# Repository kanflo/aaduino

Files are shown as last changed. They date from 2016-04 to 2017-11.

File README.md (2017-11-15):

# The AAduino

<p align="center">
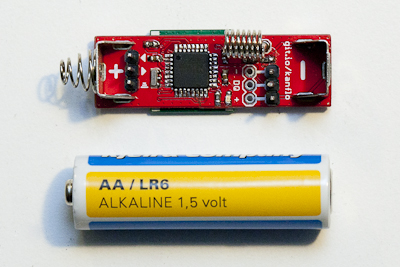
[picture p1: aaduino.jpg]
The AAduino
  
</p>

### News! Don't miss the successor of the AAduino, the [AAduino Zero](https://github.com/kanflo/aaduino-zero).

The AAduino is an wireless Arduino clone the size of an AA battery with Keystone battery terminals rotated 180° to act as positive and negative terminals. It is meant to go inside a 3xAA battery holder creating a very small wireless node.

Powered by an ATMega328p, it is fitted with an RFM69CW companion, two DS18B20 temperature sensors and an indicator LED.

Included in this repository is the schematics, bill of material and a sample program to test the hardware.
If you want solder up one yourself you can buy most of what is needed through the links on the [Kitnic page](https://kitnic.it/boards/github.com/kanflo/aaduino).

If you are looking for an easy way to order the PCBs only, please order from [DirtyPCBs.com](http://dirtypcbs.com/view.php?share=18116&accesskey=5cb9ea9c4754e5c9102b4350393b244e) and I will receive a $1 credit :)

The accompanying blog post is [here](http://johan.kanflo.com/the-aaduino).

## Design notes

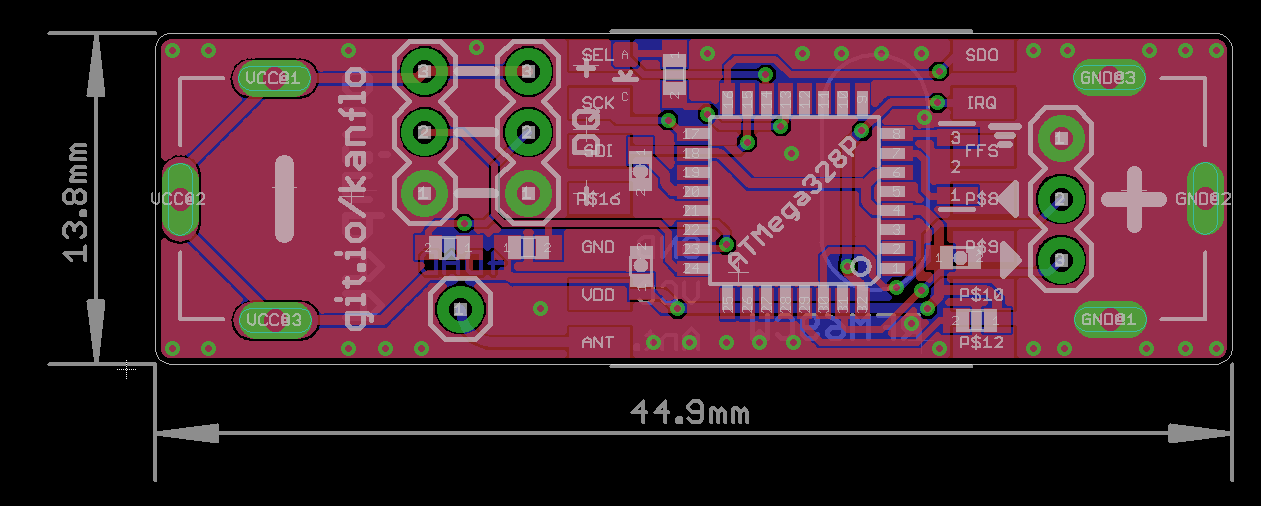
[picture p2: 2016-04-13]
hardware/aaduino-v2.png

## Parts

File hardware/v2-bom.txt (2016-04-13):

Part Value           Device                    Package                              Description           PROD_ID   VALUE     
ANT  M01PTH          M01PTH                    1X01                                 Header 1                                  
C1   0.1uF           0.1UF-25V(+80/-20%)(0603) 0603-CAP                             CAP-00810             CAP-00810 0.1uF     
C2   0.1uF           0.1UF-25V(+80/-20%)(0603) 0603-CAP                             CAP-00810             CAP-00810 0.1uF     
C3   0.1uF           0.1UF-25V(+80/-20%)(0603) 0603-CAP                             CAP-00810             CAP-00810 0.1uF     
J1   KEYSTONE-629    KEYSTONE-629              KEYSTONE_AA_AAA_BATTERY_TERMINAL-629 Keystone 629                              
J2   KEYSTONE-637    KEYSTONE-637              KEYSTONE_AA_AAA_BATTERY_TERMINAL-637 Keystone 637                              
JP1                  M03PTH                    1X03                                 Header 3                                  
JP2                  M03PTH                    1X03                                 Header 3                                  
JP3                  M03PTH                    1X03                                 Header 3                                  
LED1                 LED0603                   LED-0603                             LEDs                                      
R1   10k             RESISTOR0603-RES          0603-RES                             Resistor                                  
R2   1k8             RESISTOR0603-RES          0603-RES                             Resistor                                  
R3   4k7             RESISTOR0603-RES          0603-RES                             Resistor                                  
R4   4k7             RESISTOR0603-RES          0603-RES                             Resistor                                  
U1   ATMEGA328P      ATMEGA328_SMT             TQFP32-08                            32-Pin Atmega328 part IC-09069  ATMEGA328P
U2   RFM12B          RFM12B                    RFM12B                                                                         
U3   RESONATOR_8MHZ  RESONATOR_8MHZ            RESONATOR_SMD                                                                  

Oh, and if you want to build an AAduino, the markings for UART RX/TX got mixed up on the silk screen :-/

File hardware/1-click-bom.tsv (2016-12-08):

References | Qty | Description | Manufacturer | MPN | Digikey | Mouser | RS | Newark | Farnell
LED1 | 1 | LED 0603 | Rohm | SML-D12Y8WT86 | 511-1582-1-ND | 5988150107F | 7008023 | 75R0585 | 1465989
C1, C2, C3 | 3 | 0.1UF 25V 0603 | AVX | 06033C104KAT2A | 478-3714-1-ND | 58106033C104JAT2A | 4646379 | 47Y9715 | 317287
R1 | 1 | Resistor 10k 0603 | Vishay | MCT0603MD1001BP100 | MCT0603-10K-MBCT-ND | 594MCT0603MD1002BP1 | 6845604 | 15R2055 | 2321085
R2 | 1 | Resistor 1.8k 0603 | Panasonic | ERJ-3EKF1801V | P1.80KHCT-ND | 279CPF0603B1K8E1 | 8206782 | 80P3903 | 1697379
R3, R4 | 2 | Resistor 4.7k 0603 | Yageo | RC0603FR-074K7L | 311-4.70KHRCT-ND | 667ERJP03F4701V | 8206865 | 24T7159 | 2281415
U1 | 1 | ATMEGA328 TQFP32 | Atmel | ATMEGA328P-AU | ATMEGA328P-AU-ND | 556ATMEGA328PAU | 6963092 | 68T2935 | 1715486
J1 | 1 | Battery contact, negative | KEYSTONE | 629 | 36-629-ND | 534629 | 2050057 | 98B5924 | 1696977
J2 | 1 | Battery contact, positive | KEYSTONE | 637 | 36-637-ND | 534637 | 3670602 | 99H8361
U3 | 1 | 8 Mhz resonator | Murata | CSTCE8M00G52-R0 | 490-5994-1-ND | 81CSTCE8M00G52R0 | 7214824 | 87X8659 | 2443268
U2 | 1 | RFM69CW module from eBay |  | RFM69CW

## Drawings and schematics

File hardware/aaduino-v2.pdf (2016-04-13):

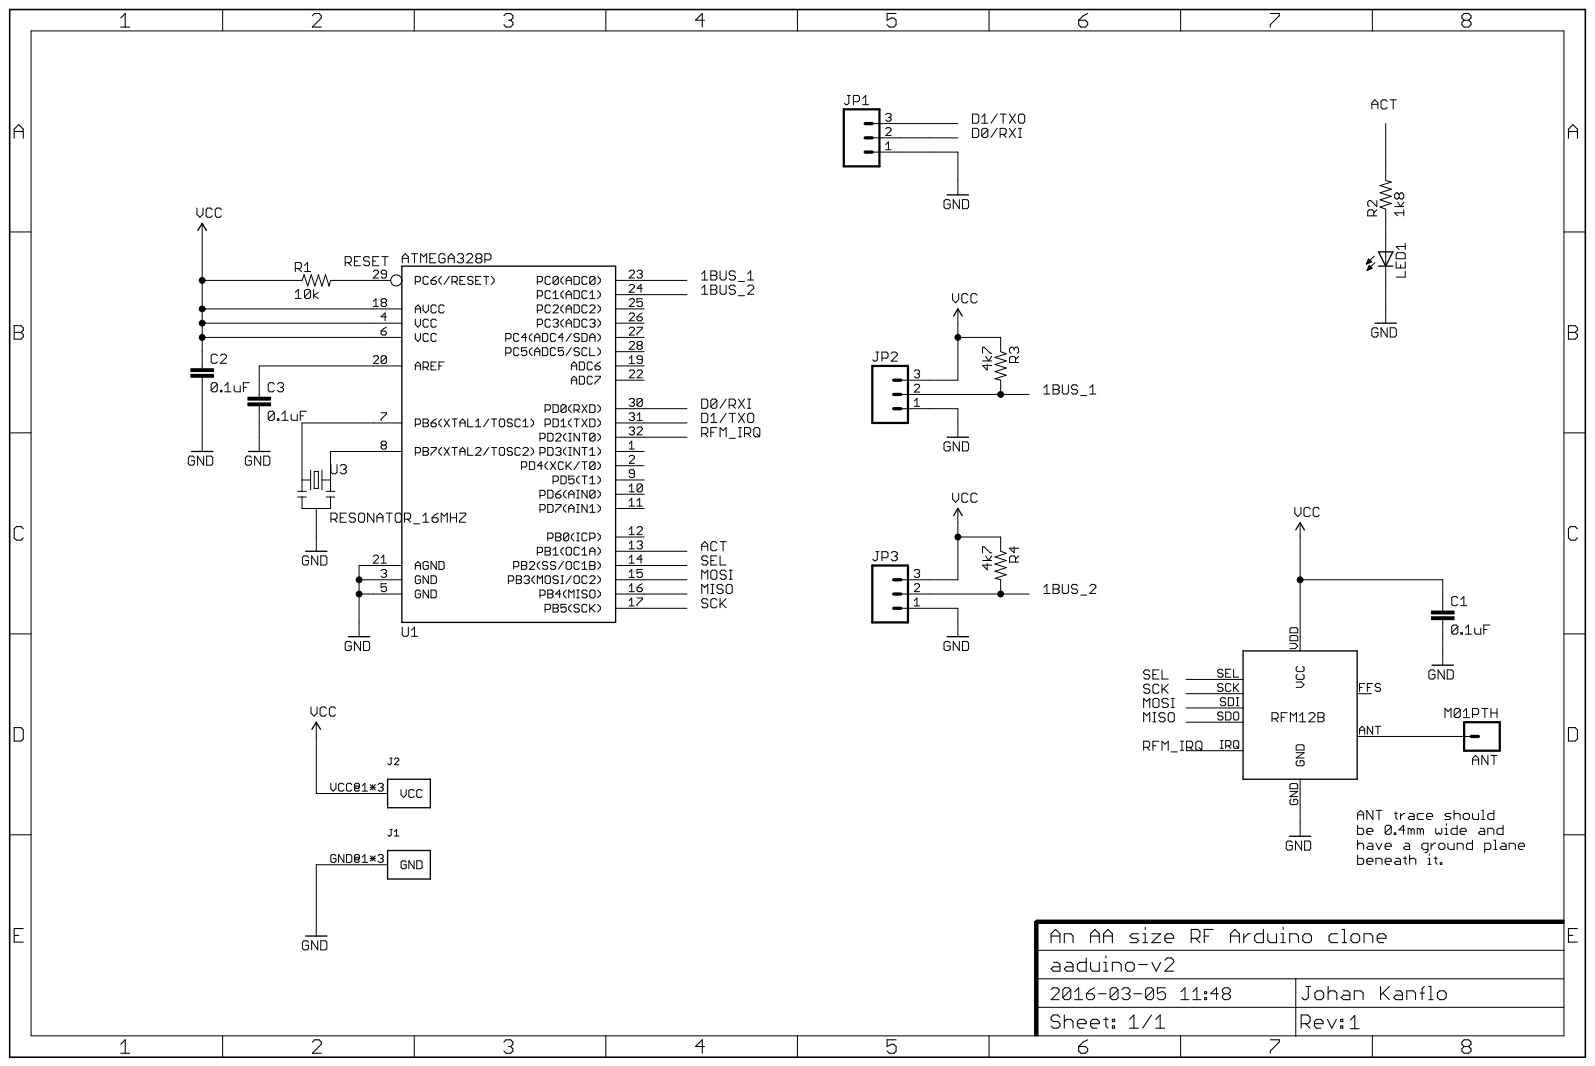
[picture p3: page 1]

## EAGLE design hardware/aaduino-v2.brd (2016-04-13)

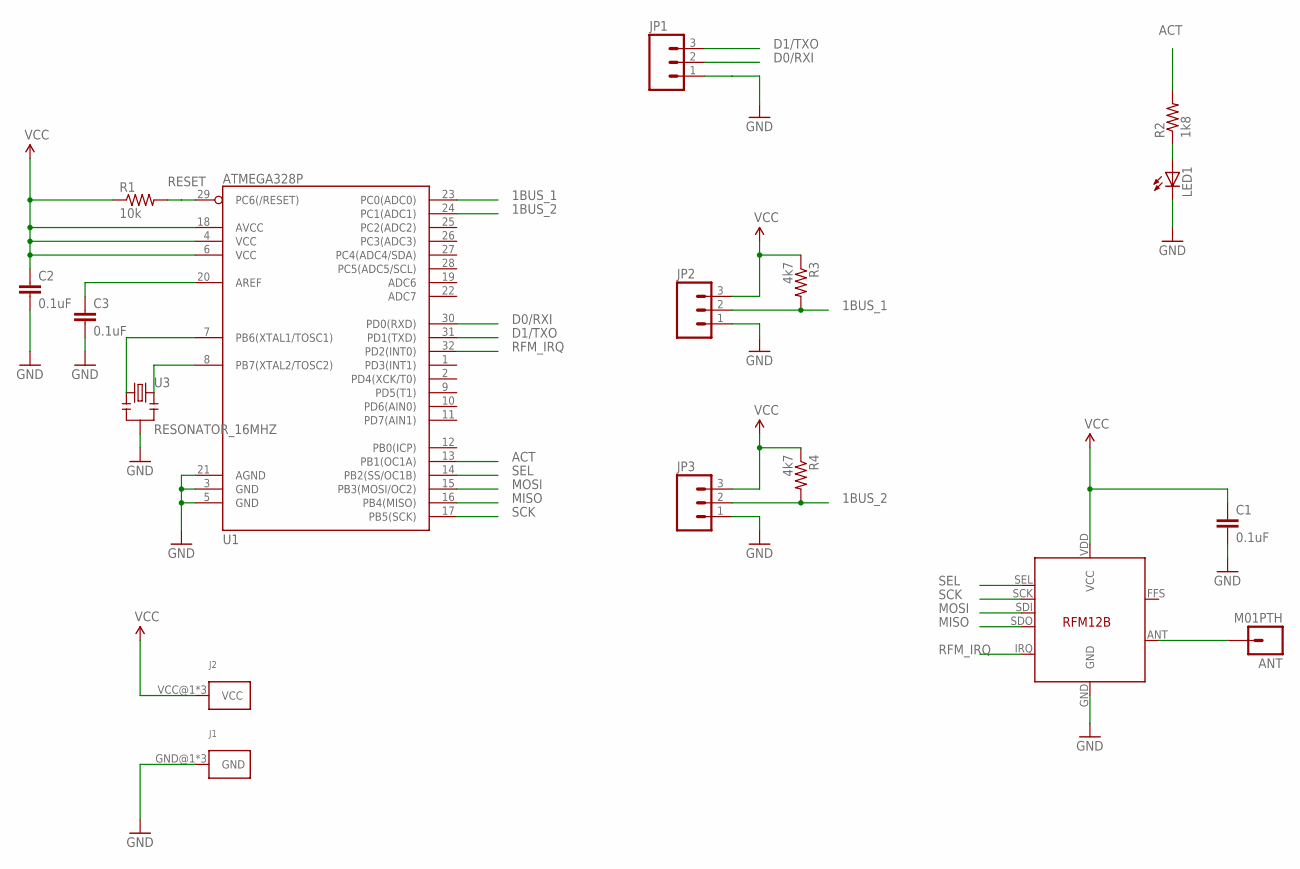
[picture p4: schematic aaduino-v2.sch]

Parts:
ANT: M01PTH; 1X01
C1, C2, C3: 0.1uF; 0603-CAP
J1: KEYSTONE-629; KEYSTONE_AA_AAA_BATTERY_TERMINAL-629
J2: KEYSTONE-637; KEYSTONE_AA_AAA_BATTERY_TERMINAL-637
JP1, JP2, JP3: M03PTH; 1X03
LED1: LED0603; LED-0603
R1: 10k; 0603-RES
R2: 1k8; 0603-RES
R3, R4: 4k7; 0603-RES
U1: ATMEGA328P; TQFP32-08
U2: RFM12B
U3: RESONATOR_16MHZ; RESONATOR_SMD

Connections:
1BUS_1: JP2.2, R3.2, U1.23 (PC0(ADC0))
1BUS_2: JP3.2, R4.2, U1.24 (PC1(ADC1))
ACT: R2.2, U1.13 (PB1(OC1A))
D0/RXI: JP1.2, U1.30 (PD0(RXD))
D1/TXO: JP1.3, U1.31 (PD1(TXD))
GND: C1.2, C2.2, C3.2, J1.GND@1, J1.GND@2, J1.GND@3, JP1.1, JP2.1, JP3.1, LED1.C, U1.3 (GND), U1.5 (GND), U1.21 (AGND), U2.GND, U3.2
MISO: U1.16 (PB4(MISO)), U2.SDO
MOSI: U1.15 (PB3(MOSI/OC2)), U2.SDI
unnamed: LED1.A, R2.1
unnamed: C3.1, U1.20 (AREF)
unnamed: U1.7 (PB6(XTAL1/TOSC1)), U3.1
unnamed: U1.8 (PB7(XTAL2/TOSC2)), U3.3
unnamed: ANT.1, U2.ANT
RESET: R1.2, U1.29 (PC6(/RESET))
RFM_IRQ: U1.32 (PD2(INT0)), U2.IRQ
SCK: U1.17 (PB5(SCK)), U2.SCK
SEL: U1.14 (PB2(SS/OC1B)), U2.SEL
VCC: C1.1, C2.1, J2.VCC@1, J2.VCC@2, J2.VCC@3, JP2.3, JP3.3, R1.1, R3.1, R4.1, U1.4 (VCC), U1.6 (VCC), U1.18 (AVCC), U2.VDD (VCC)

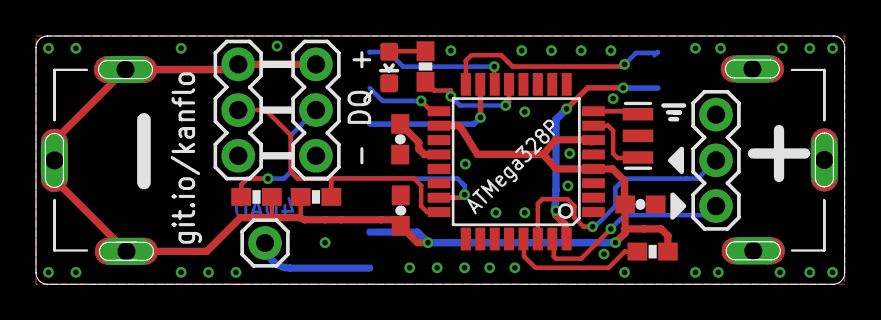
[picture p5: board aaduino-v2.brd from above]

Board: 2 copper layers, 44.9 x 13.8 mm, 17 parts (1 on the bottom side), 18 nets.

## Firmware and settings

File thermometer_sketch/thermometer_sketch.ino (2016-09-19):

/*

Simple thermometer demo for the AAduino

Probes the RFM69C radio and both DS18B20s and starts radio transmission of the
two temperature sensor readings every 2.5s

*/

#include <RFM69.h>
#include <SPI.h>
#include <OneWire.h>
#include <DallasTemperature.h>


// Network credentials
#define GATEWAYID   1
#define NODEID      42
#define NETWORKID   100
#define FREQUENCY   RF69_868MHZ
#define KEY         "sampleEncryptKey" // 16 bytes

int led = 9;

OneWire ds1(A1); // Nearest the negative terminal on the AAduino
OneWire ds2(A0);
DallasTemperature sensor1(&ds1);
DallasTemperature sensor2(&ds2);


bool promiscuousMode = false; //set to 'true' to sniff all packets on the same network

RFM69 radio;

// the setup routine runs once when you press reset:
void setup() {         
  int radio_temp;  
  // initialize the digital pin as an output.
  pinMode(led, OUTPUT);
  led_flash();
  delay(150);
  led_flash();
  delay(150);
  led_flash();
  Serial.begin(115200);
  Serial.println("aaduino!");
  Serial.println("RFM init!");
  radio.initialize(FREQUENCY,NODEID,NETWORKID);
  //radio.setHighPower(); //uncomment only for RFM69HW!
  radio.encrypt(KEY);
  radio.promiscuous(promiscuousMode);
  Serial.print("Radio temperature is ");
  radio_temp = (int) radio.readTemperature(-1);
  Serial.print(radio_temp);
  Serial.println("");
  sensor1.begin();
  sensor2.begin();
}

void led_flash() {
  digitalWrite(led, HIGH);
  delay(50);
  digitalWrite(led, LOW);
}

typedef struct {		
  int           node_id;
  unsigned long counter;
  int  rfm_temp;
  int  temp0;
  int  temp1;
} Payload;

unsigned int counter = 0;
long lastPeriod = -1;
Payload packet;
int xmit_period_ms = 2500;

// the loop routine runs over and over again forever:
void loop() {
  float temp;
  int currPeriod = millis() / xmit_period_ms;
  if (currPeriod != lastPeriod) {
    sensor1.requestTemperatures();
    sensor2.requestTemperatures();
    packet.node_id = NODEID;
    packet.counter = counter++;
    packet.rfm_temp = (int) radio.readTemperature(-1) * 10;
    temp = sensor1.getTempCByIndex(0);
    if ((int) temp == -127) {
      packet.temp0 = 0xffff;
    } else {
      packet.temp0 = temp * 10;
    }
    temp = sensor2.getTempCByIndex(0);
    if ((int) temp == -127) {
      packet.temp1 = 0xffff;
    } else {
      packet.temp1 = temp * 10;
    }

    Serial.print("temp1:");
    Serial.println(packet.temp0);
    Serial.print("temp2:");
    Serial.println(packet.temp1);
    Serial.print("Sending struct (");
    Serial.print(sizeof(packet));
    Serial.print(" bytes) ... ");
    if (radio.sendWithRetry(GATEWAYID, (const void*)(&packet), sizeof(packet))) {
      Serial.print(" ok!");
    } else {
      Serial.print(" nothing...");
    }
    Serial.println();
    led_flash();
    lastPeriod = currPeriod;
  }
}

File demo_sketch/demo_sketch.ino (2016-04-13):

/*

Simple hardware bringup program for the AAduino.
Probes the RFM69C radio and both DS18B20s and starts radio reception with the credentials below.

*/

#include <RFM69.h>
#include <SPI.h>
#include <OneWire.h>


// Network credentials
#define NODEID      42
#define NETWORKID   101
#define FREQUENCY   RF69_868MHZ
#define KEY         "sampleEncryptKey" // 16 bytes

int led = 9;

OneWire ds1(A1); // Nearest the negative terminal on the AAduino
OneWire ds2(A0);


bool promiscuousMode = true; //set to 'true' to sniff all packets on the same network

RFM69 radio;

void ds18b20_test_a1()
{
  byte i;
  byte present = 0;
  byte type_s;
  byte data[12];
  byte addr[8];
  float celsius, fahrenheit;
  
  if ( !ds1.search(addr)) {
    Serial.println("No more addresses.");
    Serial.println();
    ds1.reset_search();
    delay(250);
    return;
  }
  
  Serial.print("ROM =");
  for( i = 0; i < 8; i++) {
    Serial.write(' ');
    Serial.print(addr[i], HEX);
  }

  if (OneWire::crc8(addr, 7) != addr[7]) {
      Serial.println("CRC is not valid!");
      return;
  }
  Serial.println();
 
  // the first ROM byte indicates which chip
  switch (addr[0]) {
    case 0x10:
      Serial.println("  Chip = DS18S20");  // or old DS1820
      type_s = 1;
      break;
    case 0x28:
      Serial.println("  Chip = DS18B20");
      type_s = 0;
      break;
    case 0x22:
      Serial.println("  Chip = DS1822");
      type_s = 0;
      break;
    default:
      Serial.println("Device is not a DS18x20 family device.");
      return;
  }

  ds1.reset();
  ds1.select(addr);
  ds1.write(0x44, 1);        // start conversion, with parasite power on at the end
  
  delay(1000);     // maybe 750ms is enough, maybe not
  // we might do a ds1.depower() here, but the reset will take care of it.
  
  present = ds1.reset();
  ds1.select(addr);    
  ds1.write(0xBE);         // Read Scratchpad

  Serial.print("  Data = ");
  Serial.print(present, HEX);
  Serial.print(" ");
  for ( i = 0; i < 9; i++) {           // we need 9 bytes
    data[i] = ds1.read();
    Serial.print(data[i], HEX);
    Serial.print(" ");
  }
  Serial.print(" CRC=");
  Serial.print(OneWire::crc8(data, 8), HEX);
  Serial.println();

  // Convert the data to actual temperature
  // because the result is a 16 bit signed integer, it should
  // be stored to an "int16_t" type, which is always 16 bits
  // even when compiled on a 32 bit processor.
  int16_t raw = (data[1] << 8) | data[0];
  if (type_s) {
    raw = raw << 3; // 9 bit resolution default
    if (data[7] == 0x10) {
      // "count remain" gives full 12 bit resolution
      raw = (raw & 0xFFF0) + 12 - data[6];
    }
  } else {
    byte cfg = (data[4] & 0x60);
    // at lower res, the low bits are undefined, so let's zero them
    if (cfg == 0x00) raw = raw & ~7;  // 9 bit resolution, 93.75 ms
    else if (cfg == 0x20) raw = raw & ~3; // 10 bit res, 187.5 ms
    else if (cfg == 0x40) raw = raw & ~1; // 11 bit res, 375 ms
    //// default is 12 bit resolution, 750 ms conversion time
  }
  celsius = (float)raw / 16.0;
  fahrenheit = celsius * 1.8 + 32.0;
  Serial.print("  Temperature = ");
  Serial.print(celsius);
  Serial.print(" Celsius, ");
  Serial.print(fahrenheit);
  Serial.println(" Fahrenheit");
}

void ds18b20_test_a0()
{
  byte i;
  byte present = 0;
  byte type_s;
  byte data[12];
  byte addr[8];
  float celsius, fahrenheit;
  
  if ( !ds2.search(addr)) {
    Serial.println("No more addresses.");
    Serial.println();
    ds2.reset_search();
    delay(250);
    return;
  }
  
  Serial.print("ROM =");
  for( i = 0; i < 8; i++) {
    Serial.write(' ');
    Serial.print(addr[i], HEX);
  }

  if (OneWire::crc8(addr, 7) != addr[7]) {
      Serial.println("CRC is not valid!");
      return;
  }
  Serial.println();
 
  // the first ROM byte indicates which chip
  switch (addr[0]) {
    case 0x10:
      Serial.println("  Chip = DS18S20");  // or old DS1820
      type_s = 1;
      break;
    case 0x28:
      Serial.println("  Chip = DS18B20");
      type_s = 0;
      break;
    case 0x22:
      Serial.println("  Chip = DS1822");
      type_s = 0;
      break;
    default:
      Serial.println("Device is not a DS18x20 family device.");
      return;
  }

  ds2.reset();
  ds2.select(addr);
  ds2.write(0x44, 1);        // start conversion, with parasite power on at the end
  
  delay(1000);     // maybe 750ms is enough, maybe not
  // we might do a ds2.depower() here, but the reset will take care of it.
  
  present = ds2.reset();
  ds2.select(addr);    
  ds2.write(0xBE);         // Read Scratchpad

  Serial.print("  Data = ");
  Serial.print(present, HEX);
  Serial.print(" ");
  for ( i = 0; i < 9; i++) {           // we need 9 bytes
    data[i] = ds2.read();
    Serial.print(data[i], HEX);
    Serial.print(" ");
  }
  Serial.print(" CRC=");
  Serial.print(OneWire::crc8(data, 8), HEX);
  Serial.println();

  // Convert the data to actual temperature
  // because the result is a 16 bit signed integer, it should
  // be stored to an "int16_t" type, which is always 16 bits
  // even when compiled on a 32 bit processor.
  int16_t raw = (data[1] << 8) | data[0];
  if (type_s) {
    raw = raw << 3; // 9 bit resolution default
    if (data[7] == 0x10) {
      // "count remain" gives full 12 bit resolution
      raw = (raw & 0xFFF0) + 12 - data[6];
    }
  } else {
    byte cfg = (data[4] & 0x60);
    // at lower res, the low bits are undefined, so let's zero them
    if (cfg == 0x00) raw = raw & ~7;  // 9 bit resolution, 93.75 ms
    else if (cfg == 0x20) raw = raw & ~3; // 10 bit res, 187.5 ms
    else if (cfg == 0x40) raw = raw & ~1; // 11 bit res, 375 ms
    //// default is 12 bit resolution, 750 ms conversion time
  }
  celsius = (float)raw / 16.0;
  fahrenheit = celsius * 1.8 + 32.0;
  Serial.print("  Temperature = ");
  Serial.print(celsius);
  Serial.print(" Celsius, ");
  Serial.print(fahrenheit);
  Serial.println(" Fahrenheit");
}

// the setup routine runs once when you press reset:
void setup() {                
  // initialize the digital pin as an output.
  pinMode(led, OUTPUT);
  led_flash();
  delay(150);
  led_flash();
  delay(150);
  led_flash();
  Serial.begin(115200);
  Serial.println("aaduino!");
  Serial.println("RFM init!");
  radio.initialize(FREQUENCY,NODEID,NETWORKID);
  //radio.setHighPower(); //uncomment only for RFM69HW!
  radio.encrypt(KEY);
  radio.promiscuous(promiscuousMode);
  Serial.print("Radio temperature is ");
  Serial.print(radio.readTemperature(-1));
  Serial.println("");
  Serial.println("DS18B20 init A0");
  ds18b20_test_a0();
  Serial.println("DS18B20 init A1");
  ds18b20_test_a1();
}

void led_flash() {
  digitalWrite(led, HIGH);
  delay(50);
  digitalWrite(led, LOW);
}
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

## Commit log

2016-04-13 Added HW and SW
    [aaduino-v2.brd, aaduino-v2.sch]
2016-08-18 Made compatible with kitnic.it
    [1-click-bom.tsv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]
2016-08-31 Fixed up 1-click-bom
    [1-click-bom.tsv]
2016-09-20 Corrected RFM69C to RFM69CW
    [1-click-bom.tsv]

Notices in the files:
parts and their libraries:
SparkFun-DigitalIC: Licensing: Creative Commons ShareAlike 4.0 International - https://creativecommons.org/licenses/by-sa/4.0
